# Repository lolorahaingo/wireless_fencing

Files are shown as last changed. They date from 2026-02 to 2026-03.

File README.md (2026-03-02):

<p align="center">
  
  
  
  
  
</p>

# Wireless Fencing

> Replacing the wired scoring apparatus in competitive fencing with a fully wireless system built on Raspberry Pi Pico W microcontrollers.

---

## The Problem

In competitive foil fencing, every touch is detected by an electronic scoring apparatus connected to both fencers through **15-meter retractable cables**. These cables restrict movement, require constant maintenance, and make the sport inaccessible outside of dedicated venues.

**The fundamental challenge of going wireless:** without a physical wire connecting both fencers, there is **no common electrical ground** between them. The traditional system relies on DC circuits that require this shared reference. A completely different detection approach is needed.

---

## The Solution

Each fencer wears a **Raspberry Pi Pico W** that generates unique **AC square wave frequencies** on their conductive surfaces (lame/cuirasse). When a fencer's foil tip touches the opponent's valid target, the frequency is detected through the foil's internal wiring and identified — all without any electrical connection between the two fencers.

```
                    ┌─────────────────────────────────────────────────────────┐
                    │                    NO WIRE BETWEEN FENCERS              │
                    │                                                         │
  FENCER A          │          WiFi UDP            │          FENCER B        │
 ┌──────────┐       │       ┌──────────┐           │       ┌──────────┐      │
 │ Pico W   │       │       │ CENTRAL  │           │       │ Pico W   │      │
 │          │  ─ ─ ─│─ ─ ─ >│ Pico W   │< ─ ─ ─ ─ │─ ─ ─  │          │      │
 │ Generates│       │       │          │           │       │ Generates│      │
 │ Freq A   │       │       │ Arbitrate│           │       │ Freq B   │      │
 │ on lame  │       │       │ & Score  │           │       │ on lame  │      │
 └────┬─────┘       │       └──────────┘           │       └────┬─────┘      │
      │             │                                           │            │
   ┌──┴──┐          │                                        ┌──┴──┐         │
   │LAME │ ← Freq A │    Foil tip touches lame →             │LAME │ ← Freq B
   │     │          │    Freq detected = VALID TOUCH          │     │         │
   └─────┘          │                                        └─────┘         │
                    └─────────────────────────────────────────────────────────┘
```

### Why This Works

AC signals can traverse a single wire between two independently powered boards through **parasitic capacitive coupling** — the stray capacitance between the fencer's body, the floor, and the environment acts as the return path. This was the core hypothesis of the project, and it has been **experimentally validated**.

---

## System Architecture

### Per-Fencer Electronics

Each Pico W interfaces with the standard **3-wire body cord** (FIE convention) through a custom circuit with MOSFET buffers:

```
                         PICO W (RP2040)
                    ┌─────────────────────┐
                    │                     │
    ┌───────────────┤ GP14 (PWM out)      │
    │               │                     │
    │  ┌────────────┤ GP2  (interrupt in) │
    │  │            │                     │
    │  │  ┌─────────┤ GP16 (digital in)   │
    │  │  │         │                     │
    │  │  │         │ GP17 (PWM out)  ────┼──┐  (Mode Time-Division)
    │  │  │         │ GP15 (digital out)──┼──┤  (Mode Time-Division)
    │  │  │         └─────────────────────┘  │
    │  │  │                                  │
    ▼  ▼  ▼                                  ▼
 ┌──────────────────────────────────────────────┐
 │              MOSFET BUFFER STAGE              │
 │                                               │
 │   VBUS (5V)          VBUS (5V)                │
 │      │                  │                     │
 │   [100R]             [MOSFET C] ← GP15       │
 │      │                  │                     │
 │      ├─── Line A       [100R]                 │
 │      │   (red)          │                     │
 │   [MOSFET A]            ├─── Line C           │
 │      │    ← GP14        │   (green)           │
 │     GND              [MOSFET B] ← GP17       │
 │                         │                     │
 │                        GND                    │
 │                                               │
 │   GP2 ──┬── Line B (blue)                    │
 │         │                                     │
 │      [10kR] pull-down                        │
 │         │                                     │
 │        GND                                    │
 └───────────────────────────────────────────────┘
          │         │         │
          ▼         ▼         ▼
     ┌─────────────────────────────┐
     │       BODY CORD (3 wires)   │
     │                             │
     │  Line A ──── Lame/Cuirasse  │  ← emits Freq_VALID
     │  Line B ──── Foil tip       │  ← detects frequency
     │  Line C ──── Guard/shell    │  ← button detection (DC)
     └─────────────────────────────┘
```

### Detection Logic

The foil's push-button (German tip) is **normally closed**, connecting lines B and C. When the fencer presses the tip against a target, the circuit opens:

```
 BUTTON STATE          ELECTRICAL PATH              RESULT
 ─────────────────────────────────────────────────────────────
 Not pressed      B ←→ C connected (closed)     Nothing (no touch)
 (rest)           GP16 reads LOW (pulled down
                  by GP2's 10kΩ via B→C path)

 Pressed +        B isolated, tip touches        VALID TOUCH
 tip on lame      opponent's lame → Freq_VALID   (colored light)
                  detected on GP2

 Pressed +        B isolated, tip touches        No light
 tip on guard     neutral surface → Freq_NEUTRE  (annulled)

 Pressed +        B isolated, tip in air         WHITE LIGHT
 tip in air       no frequency on GP2            (off-target)
 ─────────────────────────────────────────────────────────────
```

### Communication

```
  Fencer A                                    Fencer B
  Pico W ──── WiFi UDP ────┐  ┌──── WiFi UDP ──── Pico W
                            ▼  ▼
                      ┌──────────┐
                      │ CENTRAL  │
                      │ Pico W   │
                      │          │
                      │ • AP mode│
                      │ • Lockout│  300-350ms (FIE rules)
                      │ • Dwell  │  15ms minimum contact
                      │ • Score  │
                      │ • LEDs   │
                      └──────────┘
```

- **Protocol:** Raw UDP over WiFi (ESP-NOW is Espressif-only, incompatible with Pico W's CYW43439 chip)
- **Topology:** Central Pico W acts as WiFi Access Point
- **Target latency:** < 20ms (well within the 300ms lockout window)

---

## Engineering Journey

This project follows a rigorous **hypothesis-driven** approach: each phase validates a specific assumption before building on it. Several discoveries forced significant architecture redesigns.

### Phase 0 — Proof of Concept

| Phase | Test | Result |
|---|---|---|
| 0.1 | Frequency detection on same board (Arduino Mega) | 25 kHz detected via interrupt counting |
| 0.2 | Multi-frequency classification (20/25/40 kHz) | 3 frequencies distinguished with ±2 kHz tolerance |
| 0.3 | **Detection without common ground** (Mega → Pico W) | ~19 kHz detected through parasitic coupling |
| 0.4 | Pico-to-Pico without common ground | **20,020 Hz** — near-perfect with 10kΩ pull-down |

> **Key validation:** AC signals traverse a single wire between independently powered boards. The core hypothesis holds.

### Phase 1 — Real Equipment Integration

This is where the real engineering challenges emerged:

#### Challenge 1: Capacitive Load of the Lame

The conductive lame (target vest) forms a large parasitic capacitor with the environment. The Pico's GPIO (3.3V, 12mA) couldn't drive it at 20 kHz.

```
 Problem:  GPIO direct → lame         5-7 kHz (should be 20 kHz)
 Solution: MOSFET 2N7000 buffer       20 kHz perfect
           + 100Ω pull-up to 5V
           (10kΩ pull-up was too weak — only 0.5mA couldn't charge
            the parasitic capacitance fast enough)
```

#### Challenge 2: Parasitic B↔C Coupling Inside the Foil

Lines B and C run millimeters apart inside the blade groove, forming a parasitic capacitor. The 5V/50mA buffered signal on line C leaked to line B, making it impossible to emit on C and detect on B simultaneously.

```
 Before (4-pin design):
   GP14 → emit on A (lame)     ✓
   GP2  ← detect on B (tip)    ✗ sees C's signal via parasitic coupling
   GP16 → emit on C (guard)    ✗ leaks to B
   GP17 ← detect button        ✗ always sees 20 kHz

 After (3-pin redesign):
   GP14 → emit on A (lame)     ✓ MOSFET buffer
   GP2  ← detect on B (tip)    ✓ clean signal, no C emission
   GP16 ← detect button (DC)   ✓ exploits DC vs AC difference
```

> **Insight:** Capacitive coupling blocks DC but passes AC. The mechanical button passes DC but the parasitic coupling doesn't. By reading DC on line C, we can detect the button state without any interference.

#### Challenge 3: 5V Signal Crashing the Pico

When the foil tip touches the lame (5V via MOSFET), the signal travels back through the button to GP16, exceeding the 3.3V GPIO tolerance and causing a latch-up reset.

```
 Solution: 10kΩ series resistor on GP16
           Limits current to 0.5mA (protection diodes handle it)
           Button reading still works: 0.47V (LOW) / 2.75V (HIGH)
```

#### Challenge 4: Signal Attenuation in the Foil

The foil's internal wire (~90cm in the blade groove) runs ~1mm from the metal blade, forming a **~10nF parasitic capacitor** that shunts AC signals to ground.

```
 Frequency    Impedance (10nF)    Detection
 ──────────────────────────────────────────
 20 kHz       ~800Ω               1,700 Hz detected (massive loss)
  5 kHz       ~3.2kΩ              500-1,700 Hz (still too much loss)
  1 kHz       ~16kΩ               should pass (to be validated)
```

> **Current blocker:** Frequencies must be lowered from 20-40 kHz to ~1-3 kHz. Experimental validation pending.

### Progress Overview

```
 Phase 0   Proof of Concept                          ██████████ DONE
 Phase 1   Real Equipment Integration                ████████░░ 80% (freq. validation pending)
 Phase 2   Complete System (Simple + Time-Division)  ░░░░░░░░░░ TODO
 Phase 3   WiFi UDP Communication                    ░░░░░░░░░░ TODO
 Phase 4   FIE Arbitration Logic                     ░░░░░░░░░░ TODO
 Phase 5   Full 2-Fencer Integration                 ░░░░░░░░░░ TODO
 Phase 6   Polish (LEDs, battery, enclosure)         ░░░░░░░░░░ TODO
```

---

## Key Technical Decisions

| Decision | Choice | Why |
|---|---|-----|
| **Detection method** | Interrupt pulse counting (not Goertzel/FFT) | Signal is square wave — energy spread across harmonics makes FFT unreliable. Counting rising edges is simpler and more robust |
| **Signal generation** | RP2040 hardware PWM (not `tone()`) | `tone()` on Pico W is imprecise at high frequencies (~14 kHz instead of 20 kHz). Hardware PWM is cycle-exact |
| **Communication** | WiFi UDP (not ESP-NOW) | ESP-NOW is Espressif-only. Pico W uses Infineon CYW43439 — must use standard WiFi |
| **Button detection** | DC reading on line C (not RC filter) | RC filter approach failed due to B↔C parasitic coupling. DC reading exploits the physical difference between capacitive coupling (blocks DC) and mechanical switch (passes DC) |
| **Current buffer** | 2N7000 MOSFET + 100Ω pull-up to 5V | GPIO can't drive capacitive loads. 100Ω provides ~50mA — enough to charge/discharge parasitic capacitance at 20 kHz |
| **Receiver pull-down** | External 10kΩ (not internal ~50kΩ) | Internal pull-down too weak for 3.3V signals without common ground. 10kΩ gives perfect detection |

---

## Hardware

| Component | Role | Qty |
|---|---|-----|
| Raspberry Pi Pico W | Fencer controller + central arbiter | 3 |
| 2N7000 N-MOSFET | Current buffer for driving conductive surfaces | 3 per fencer |
| 100Ω resistors | MOSFET pull-ups + gate protection | 4 per fencer |
| 10kΩ resistors | Receiver pull-down + GP16 protection | 2 per fencer |
| Electric foil (German tip) | Standard FIE weapon | 2 |
| Body cord (3-wire) | Standard FIE body cord | 2 |
| Conductive lame | Valid target surface | 2 |

A custom PCB is being designed in **KiCad 9** (`wireless_fencing_fencer/`).

---

## Project Structure

```
wireless_fencing/
├── phase0_1_freq_interrupt/     # Frequency detection on Arduino Mega
├── phase0_2_freq_detection/     # Multi-frequency classification
├── phase0_3_no_common_gnd/      # No-common-ground validation
│   ├── mega_generator/          #   Arduino Mega signal generator
│   └── pico_receiver/           #   Pico W receiver
├── phase0_4_pico_to_pico/       # Pico-to-Pico validation
│   ├── pico_generator/          #   PWM hardware generator
│   └── pico_receiver/           #   Interrupt-based receiver
├── phase1_5_button_detect/      # Button detection (RC approach — abandoned)
├── phase1_6_button_dc/          # Button detection via DC + diagnostic tests
├── wireless_fencing_fencer/     # KiCad 9 PCB design
├── gpio_test/                   # GPIO validation utilities
├── PROJECT_PLAN.md              # Detailed engineering log (1000+ lines)
└── CLAUDE.md                    # AI assistant context file
```

---

## FIE Compliance

The system targets compliance with FIE (International Fencing Federation) timing specifications for foil:

| Parameter | FIE Specification | System Target |
|---|---|---|
| Dwell time (minimum contact) | 15ms ± 0.5ms | Measured per touch |
| Lockout time | 300-350ms | Configurable timer on central |
| Communication latency | — | < 20ms (UDP) |

---

## Tech Stack

- **Microcontroller:** Raspberry Pi Pico W (RP2040, Cortex-M0+, 133 MHz)
- **Framework:** Arduino (earlephilhower core)
- **Build system:** PlatformIO
- **Signal generation:** RP2040 hardware PWM (`hardware/pwm.h`)
- **PCB design:** KiCad 9
- **Communication:** WiFi UDP (CYW43439)

---

<p align="center">
  <i>An ongoing R&D project exploring the intersection of embedded systems, signal processing, and competitive sports.</i>
</p>

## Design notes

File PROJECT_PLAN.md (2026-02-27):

# Projet Escrime Sans Fil (Wireless Fencing)

## Contexte & Objectif

Concevoir un systeme d'arbitrage electronique sans fil pour le **fleuret** (escrime),
a base de **Raspberry Pi Pico W**, qui remplace le systeme filaire traditionnel.

La problematique principale du sans-fil est l'**absence de masse commune** entre les
deux tireurs. La solution retenue est la **detection de frequence** : chaque tireur
porte un Pico W qui genere des signaux carres AC sur ses surfaces conductrices (cuirasse
et coque du fleuret). Le fleuret adverse detecte ces frequences au contact, ce qui
permet d'identifier la nature de la touche sans connexion physique entre les tireurs.

---

## Decouvertes & Validations Cles

### Detection sans GND commun : VALIDEE (Phase 0.3 + 0.4)

**Phase 0.3** (Mega 5V → Pico W) : Arduino Mega (adaptateur secteur) genere 20 kHz
sur Pin 9, Pico W (USB sur Mac batterie) detecte sur GPIO 2. Un seul fil, aucun GND
commun. Resultat : ~18500-19700 Hz detecte (~95% des fronts). Le signal 5V du Mega
a assez d'amplitude pour franchir le seuil du GPIO recepteur.

**Phase 0.4** (Pico W 3.3V → Pico W) : Deux Pico W, alimentations separees (secteur
vs USB Mac). Resultat initial : seulement ~16 kHz detecte (~80% des fronts). Le signal
3.3V est trop faible sans GND commun pour declencher tous les fronts montants.

**Solution : resistance pull-down 10kΩ** sur le pin recepteur (entre GPIO 2 et GND
du Pico recepteur). Cette resistance tire le pin vers le bas, augmentant l'excursion
du signal couple et permettant au GPIO de detecter tous les fronts.

**Resultat avec pull-down 10kΩ** : 20 020 Hz detecte — precision quasi parfaite,
detection instantanee, equivalent au test avec GND commun.

| Test | Signal | Sans pull-down | Avec pull-down 10kΩ |
|---|---|---|---|
| Mega 5V → Pico | 20 kHz | ~19 kHz (95%) | non teste |
| Pico 3.3V → Pico | 20 kHz | ~16 kHz (80%) | **20 020 Hz (100%)** |
| Pico 3.3V → Pico (GND commun) | 20 kHz | 20 000 Hz exact | - |

**Implications** :
- L'hypothese fondamentale du projet est validee
- Le signal AC traverse un contact physique sans masse commune
- Une resistance pull-down 10kΩ cote recepteur est NECESSAIRE pour le Pico 3.3V
- Le couplage capacitif parasite suffit comme chemin de retour

### Charge capacitive de la cuirasse : RESOLU (Phase 1)

**Probleme** : Le GPIO du Pico (3.3V, ~12 mA max) ne peut pas driver la charge
capacitive de la cuirasse a 20 kHz. La cuirasse est une grande surface conductrice
qui forme un condensateur parasite avec tout ce qui l'entoure (siege, sol, corps).

**Tests sans buffer (GPIO direct)** :

| Test | Resultat |
|---|---|
| Pince croco ↔ fiche directe (sans cuirasse) | 20 kHz exact ✅ |
| Cuirasse posee sur siege plastique | 5-7 kHz fluctuant ❌ |
| Cuirasse suspendue en l'air | 10-19 kHz fluctuant ❌ |

**Solution : MOSFET 2N7000 + pull-up 100Ω vers VBUS (5V)**

La pull-up 10kΩ initialement prevue etait trop elevee — le courant (0.5 mA) ne
suffisait pas a recharger la capacitance parasite entre chaque front. Avec 100Ω
(50 mA max), les fronts montants sont assez rapides pour 20 kHz.

```
Circuit buffer valide :

        VBUS (5V)
            │
         [100Ω]  pull-up (10kΩ trop faible, 100Ω necessaire)
            │
            ├──────── vers cuirasse (fil de corps, ligne A ou C)
            │
        Drain (D)
            │
  GPIO ──[100Ω]── Gate (G)    2N7000 (MOSFET N-channel)
            │
        Source (S)
            │
          GND Pico
```

**Tests avec buffer MOSFET + pull-up 100Ω (cuirasse sur siege)** :

Detection via fleuret + fil de corps touchant la cuirasse :
- **20 000 - 20 200 Hz** sur la majorite des mesures → detection parfaite ✅
- Quelques mesures a 0 Hz → perte de contact physique (normal pour test a la main)
- Quelques mesures aberrantes (12 kHz, 24 kHz) → transitions de contact
  (etablissement/rupture pendant la fenetre de mesure)
- Le signal est detecte meme **bouton non presse** → comportement normal car
  B est connecte a la pointe en permanence, le bouton (normalement ferme) relie
  B a C mais ne bloque pas le signal vers GP2. La logique de filtrage par l'etat
  du bouton (GP20) est necessaire cote software.

**Resultat** : Le buffer MOSFET 2N7000 + pull-up 100Ω vers VBUS resout
completement le probleme de charge capacitive. Detection fiable a 20 kHz
a travers la cuirasse posee sur un siege, via fleuret + fil de corps.

**Historique des pull-up testees** :
- 10kΩ : insuffisant — signal 20-50 Hz cote drain (front montant trop lent)
- **100Ω : fonctionne** — 20 kHz detecte parfaitement

### Couplage parasite B↔C dans le fleuret : DECOUVERTE CRITIQUE (Phase 1.5)

**Probleme** : Quand on genere Freq_NEUTRE (20 kHz) sur la ligne C (coque/bati)
via le buffer MOSFET, le signal **fuit vers la ligne B** par couplage capacitif
parasite a l'interieur du fleuret. Les lignes B et C courent a quelques millimetres
l'une de l'autre dans la rainure de la lame, formant un condensateur parasite.

**Test Phase 1.5** : GP14 genere 20 kHz sur ligne C (MOSFET + pull-up 100Ω).
GP2 mesure la frequence sur ligne B. Resultat : **GP2 detecte ~20 000 Hz en
permanence**, meme bouton presse, meme pointe en l'air ne touchant rien.

Le signal 5V / 50 mA du buffer MOSFET est suffisamment puissant pour traverser
la capacite parasite interne B↔C du fleuret.

**Consequences** :
- On ne peut PAS emettre sur la ligne C et detecter proprement sur la ligne B
  en meme temps — les signaux se perturbent
- L'approche initiale (filtre RC sur GP16 pour detecter le bouton via
  presence/absence du 20 kHz sur B) est **invalidee** : le 20 kHz est
  toujours present sur B par couplage, que le bouton soit ferme ou ouvert
- L'architecture a 4 pins (2 PWM sortie + 2 GPIO entree) doit etre revue

**Solution retenue** : Architecture a 3 pins avec deux variantes incrementales :

- **Mode Simple (fondation)** : Pas de signal sur la ligne C. La ligne C sert
  uniquement a la detection du bouton par lecture DC. Pas de couplage parasite,
  detection propre sur GP2. Sacrifice : la coque n'emet pas Freq_NEUTRE
  (touche sur coque = blanche au lieu de "pas de lumiere").

- **Mode Time-Division (amelioration)** : Time-division sur la ligne C avec deux pins.
  GP17 emet le PWM via MOSFET (9 ms), puis est mis a LOW (1 ms) pendant que
  GP16 lit l'etat DC du bouton. Quand le bouton est detecte comme presse,
  GP17 reste a LOW et on bascule en detection de frequence pure sur GP2.
  La coque emet 90% du temps → ~18 kHz apparent pour le recepteur adverse
  (dans la tolerance ±2 kHz de NEUTRE).

Voir la section "Architecture par Tireur" pour les details.

### Signal 5V sur GP16 : crash du Pico (Phase 1.7)

**Probleme** : Quand GP16 (INPUT_PULLUP) est connecte a la ligne C et que la
pointe du fleuret touche la cuirasse alimentee (5V/20kHz via MOSFET), le signal
remonte par le chemin : cuirasse → pointe → ligne B → bouton ferme → ligne C → GP16.
Le signal 5V depasse la tolerance de 3.3V du GPIO, provoquant un **latch-up** et
un reset du Pico. Le crash est progressif : il survient quand le contact devient
franc et que le courant augmente.

**Solution** : Resistance serie **10kΩ** entre la ligne C et GP16. Limite le courant
a 0.5 mA max (5V / 10kΩ), ce que les diodes de protection internes supportent.
La lecture DC du bouton fonctionne toujours :
- Bouton ferme : 3.3V × 10k / (50k + 10k + 10k) ≈ 0.47V → LOW ✅
- Bouton presse : 3.3V × 50k / (50k + 10k) ≈ 2.75V → HIGH ✅

**Valide en Phase 1.7** : plus de crash avec la resistance serie.

### Attenuation du signal AC dans le fleuret : DECOUVERTE CRITIQUE (Phase 1.7)

**Probleme** : Le signal 20 kHz genere sur la cuirasse (5V via MOSFET buffer)
est **massivement attenue** en traversant le fil interne du fleuret. Au lieu de
20 kHz, GP2 ne detecte que ~1700 Hz. Meme a 5 kHz, le signal est attenue a
~500-1700 Hz.

**Tests de diagnostic** :

| Configuration | Frequence detectee |
|---|---|
| Fil direct (sans fleuret, sans cuirasse) | 20 000 Hz exact ✅ |
| Fil de corps seul (sans fleuret) | 20 000 Hz ✅ |
| Fleuret branche, pointe touche cuirasse | ~1 700 Hz ❌ |
| Fleuret branche, 5 kHz sur cuirasse | ~500-1 700 Hz ❌ |

Le fil de corps seul transmet parfaitement. C'est le **fil interne du fleuret**
(~90 cm dans la rainure de la lame) qui attenue le signal.

**Cause** : Le fil interne du fleuret court a ~1 mm de la lame metallique sur
toute sa longueur, formant un **condensateur parasite** estime a ~10 nF.
Ce condensateur shunt le signal AC vers la lame (ligne C / masse de l'arme)
avant qu'il n'atteigne le connecteur (ligne B).

A 20 kHz, l'impedance de 10 nF est : Zc = 1/(2π × 20000 × 10nF) ≈ **800Ω**
→ la majorite du signal est court-circuitee vers la lame.

A 1 kHz, l'impedance serait : Zc = 1/(2π × 1000 × 10nF) ≈ **16 kΩ**
→ beaucoup moins de fuite, le signal devrait passer.

**Implication** : Les frequences de 20-40 kHz sont **trop elevees** pour
traverser le fil interne du fleuret. Le systeme filaire classique (FIE)
fonctionne en DC (circuit normalement ferme, detection par rupture) et n'a
pas ce probleme. Notre approche par detection de frequence AC doit utiliser
des **frequences beaucoup plus basses** (1-3 kHz) pour que l'impedance du
condensateur parasite soit suffisamment elevee.

**Consequences** :
- Les frequences 20/25/40 kHz doivent etre **revues a la baisse**
- Les nouvelles frequences doivent rester suffisamment espacees pour la
  classification par plage de tolerance
- Le PWM hardware du RP2040 supporte ces frequences basses sans probleme
  (wrap plus grand)
- La fenetre de mesure de 50 ms reste adaptee (50 fronts a 1 kHz = suffisant)
- A valider experimentalement : tester 1 kHz, 2 kHz, 3 kHz a travers le fleuret

**Frequences candidates (a valider)** :

| Frequence | Usage | PWM wrap (125 MHz) | Impedance Zc (10nF) |
|---|---|---|---|
| 1 kHz | Freq_NEUTRE | 125 000 | 16 kΩ |
| 1.5 kHz | Freq_VALID_A | 83 333  | 10.6 kΩ |
| 2.5 kHz | Freq_VALID_B | 50 000  | 6.4 kΩ |

Ou :

| Frequence | Usage | PWM wrap (125 MHz) | Impedance Zc (10nF) |
|---|---|---|---|
| 2 kHz | Freq_NEUTRE | 62 500  | 8 kΩ |
| 3 kHz | Freq_VALID_A | 41 667  | 5.3 kΩ |
| 4 kHz | Freq_VALID_B | 31 250  | 4 kΩ |

Les frequences exactes seront determinees apres les tests experimentaux.

### Generation de signal sur Pico W : PWM hardware (pas tone())

`tone()` sur le Pico W (framework Earlephilhower) est imprecis aux hautes frequences
(~14-16 kHz au lieu de 20 kHz demande). Le **PWM hardware du RP2040** est exact :

```
Clock RP2040 = 125 MHz
freq = 125000000 / wrap   (diviser = 1)
20 kHz → wrap = 6250 → exact
25 kHz → wrap = 5000 → exact
40 kHz → wrap = 3125 → exact
```

Utiliser `hardware/pwm.h` avec `pwm_init()` au lieu de `tone()`.

### Methode de detection : Comptage par interruption (pas Goertzel)

**Goertzel est inadapte** pour ce projet : le signal genere est un signal carre
(pas sinusoidal), et l'energie est repartie sur les harmoniques. Le comptage
d'impulsions par interruption sur front montant est plus simple, plus fiable,
et parfaitement adapte aux signaux carres.

**Methode retenue** : `attachInterrupt(pin, callback, RISING)` + comptage sur
une fenetre temporelle (50 ms). La frequence = nombre_impulsions * (1000 / duree_ms).
Classification par plage de tolerance (±2 kHz).

### Frequences exactes

> **ATTENTION** : Les frequences 20/25/40 kHz ci-dessous sont les valeurs initiales,
> validees en Phase 0 (fil direct et fil de corps). Elles sont **trop elevees** pour
> traverser le fil interne du fleuret (attenuation massive, voir section "Attenuation
> du signal AC dans le fleuret"). De nouvelles frequences dans la plage 1-3 kHz
> doivent etre validees experimentalement (Phase 1.7bis). Le tableau ci-dessous
> reste comme reference historique.

| Frequence | Usage | Mega (prescaler 8) | Pico W (PWM hardware) |
|---|---|---|---|
| **20 000 Hz** | Freq_NEUTRE | OCR=49 → exact | wrap=6250 → exact |
| **25 000 Hz** | Freq_VALID_A | OCR=39 → exact | wrap=5000 → exact |
| **40 000 Hz** | Freq_VALID_B | OCR=24 → exact | wrap=3125 → exact |

Sur le Mega : `tone(pin, freq)` fonctionne car le timer est precis.
Sur le Pico W : utiliser le **PWM hardware** (`hardware/pwm.h`), pas `tone()`
qui est imprecis aux hautes frequences (~14-16 kHz au lieu de 20 kHz).

### Materiel : Pico W (RP2040), pas Pico 2W (RP2350)

Les cartes disponibles sont des **Raspberry Pi Pico W** (chip RP2040, Cortex-M0+),
et non des Pico 2W (chip RP2350, Cortex-M33). La distinction est importante pour
PlatformIO :
- Board ID : `rpipicow` (pas `rpipico2w`)
- Plateforme : `https://github.com/maxgerhardt/platform-raspberrypi.git`
- Core : `earlephilhower` (obligatoire pour attachInterrupt sur tous les GPIO,
  analogReadResolution, Serial USB, etc.)
- Upload : `picotool`
- La plateforme officielle `raspberrypi` de PlatformIO ne supporte PAS le Pico W

---

## Materiel Disponible

| Element | Statut |
|---|---|
| Arduino Mega | Disponible |
| Raspberry Pi Pico W x2 | Disponible |
| Fleuret electrique (tete allemande) | Disponible |
| Fil de corps | Disponible |
| Cuirasse / Lame (FIE standard) | Disponible |
| Connecteurs fleuret/fil de corps pour Arduino | Disponible |
| Resistances et condensateurs | Disponible |
| Piste metallique | NON disponible (sujet separe) |
| Oscilloscope / analyseur logique | NON disponible |
| 3eme Pico W (central) | A commander |

---

## Specifications FIE (Fleuret)

| Parametre | Valeur FIE |
|---|---|
| Temps de contact minimum (dwell) | 15 ms (+/- 0.5 ms) |
| Temps de blocage (lockout/cutout)  | 300-350 ms |
| Poids minimum sur la pointe | 500 g (4.90 N) - mecanique, non pertinent pour l'electronique |
| Temps de blocage epee (reference)  | 40 ms |

> Le lockout time est le temps entre la premiere touche enregistree et le moment
> ou le systeme se ferme. Si l'autre tireur touche dans cette fenetre, c'est une
> double touche. La latence de communication doit etre bien inferieure a 300 ms.

---

## Circuit Electrique du Fleuret — Systeme Filaire Standard

### Les 3 lignes du fil de corps (convention FIE)

| Ligne | Couleur schema | Nom FIE | Connecte a |
|---|---|---|---|
| A | Rouge | Lame | Lame/cuirasse de l'ADVERSAIRE (via appareil) |
| B | Bleu | Arme | Pointe du fleuret (via fil dans la rainure lame) |
| C | Vert | Masse | Bati du fleuret (coque/garde + lame de l'arme) |

### Bouton-poussoir (tete allemande) — NORMALEMENT FERME

- **Au repos** (bouton NON presse) : ligne B connectee a ligne C.
  Le courant circule de B vers C en permanence. Circuit ferme.
- **Bouton presse** : la connexion B <-> C est **rompue**.
  La ligne B n'est plus reliee qu'a ce qui touche la pointe physiquement.

### Fonctionnement du systeme filaire classique

| Situation | Etat electrique | Resultat |
|---|---|---|
| Bouton **non** presse | B connecte a C (ferme) | Rien |
| Bouton presse, pointe touche **lame adv.** | B se connecte a A (via le lame) | **Touche valide** (lumiere color) |
| Bouton presse, pointe touche **piste/arme**| B se connecte a C (via masse/piste)| **Rien** (annule) |
| Bouton presse, pointe touche **autre** | B n'est connecte a rien | **Touche non-valide** (blanche) |

---

## Adaptation Sans Fil — Architecture par Tireur

### Principe : 3 pins fonctionnels par Pico

Chaque Pico utilise les 3 lignes du fil de corps avec une correspondance 1:1.
La contrainte cle est que les lignes B et C ne peuvent pas etre utilisees
simultanement en emission et en detection (couplage parasite B↔C dans le fleuret).

| Pin Pico (GPIO) | Ligne fil de corps | Fonction |
|---|---|---|
| GP14 (PWM) | A (rouge) | Generation Freq_VALID sur cuirasse |
| GP2  (GPIO IN) | B (bleu) | Detection frequence par interruption |
| GP16 (GPIO IN) | C (vert) | Detection bouton par lecture DC |
| GP17 (PWM) | C (vert) | Mode Time-Division : emission Freq_NEUTRE via MOSFET |
| GP15 (GPIO OUT)  | — | Mode Time-Division : commutation alimentation pull-up |

### Mode Simple — Architecture de base (pas d'emission sur C)

C'est l'architecture de travail actuelle. La ligne C ne porte aucun signal,
elle sert uniquement a detecter l'etat du bouton par lecture DC.

**GP14 — Generation Freq_VALID (ligne A / rouge) — SORTIE PWM**
- Genere un signal carre a Freq_VALID (unique par tireur) sur la ligne A
- La ligne A est connectee a la cuirasse du tireur (via MOSFET buffer)
- Freq_VALID_A = 25 kHz, Freq_VALID_B = 40 kHz (valeurs initiales, a revoir → ~1-3 kHz)
- But : identifier une touche sur la surface valable de CE tireur

**GP2 — Detection frequence (ligne B / bleu) — ENTREE GPIO (interruption)**
- Detecte le signal qui arrive sur la pointe du fleuret via la ligne B
- N'est analyse que QUAND le bouton est presse (GP16)
- Comptage d'impulsions par interruption (RISING) sur une fenetre de 50 ms
- Pull-down 10kΩ entre GP2 et GND (indispensable sans GND commun)
- Classification par plage de frequence (±2 kHz avec 20-40 kHz, tolerance a reajuster avec nouvelles frequences) :
  - Freq_VALID adverse → touche valide
  - Aucune frequence → touche non-valide (blanche)

**GP16 — Detection bouton (ligne C / vert) — ENTREE GPIO (INPUT_PULLUP)**
- Connecte a la ligne C du fil de corps
- Exploite le fait que le couplage capacitif parasite **bloque le DC**
  tandis que le bouton mecanique **laisse passer le DC**
- Au repos (bouton ferme, B↔C connectes) : GP16 est tire vers LOW par
  la pull-down 10kΩ de GP2 (via le chemin C → bouton → B → pull-down)
  Tension : 3.3V × 10kΩ / (50kΩ + 10kΩ) ≈ 0.55V → LOW
- Bouton presse (B↔C ouvert) : GP16 flotte, tire vers HIGH par la
  pull-up interne (~50kΩ vers 3.3V) → HIGH
- Lecture par digitalRead(), instantanee

**Limitation de l'option 2** : la coque du fleuret n'emet pas Freq_NEUTRE.
Si la pointe adverse touche la coque, elle ne detecte aucune frequence →
touche blanche au lieu de "pas de lumiere". Acceptable pour le prototype.

### Mode Time-Division — Architecture amelioree (time-division sur C)

Evolution de l'option 2 avec deux pins supplementaires (GP17 + GP15) et
deux MOSFETs supplementaires. Le circuit est cable une seule fois ; le
passage Mode Simple → Mode Time-Division est purement logiciel.

**Probleme resolu** : en Mode Time-Division, la pull-up 100Ω du MOSFET d'emission
tire la ligne C a ~5V, ce qui ecrase la lecture DC du bouton par GP16.
Solution : un 3e MOSFET (C) controle par GP15 coupe l'alimentation de la
pull-up pendant la phase DETECT. Quand GP15 = LOW, la pull-up est
deconnectee de VBUS et GP16 peut lire le bouton proprement.

```
Phase EMIT   (9 ms) : GP15 = HIGH (pull-up alimentee)
                       GP17 = PWM → MOSFET B commute → 20 kHz sur ligne C
                       GP16 ignore (voit le signal PWM, non lu)

Phase DETECT (1 ms) : GP15 = LOW (pull-up coupee)
                       GP17 = LOW → MOSFET B bloque
                       GP16 en INPUT_PULLUP → lit l'etat DC du bouton

Si bouton detecte comme presse → BASCULE EN MODE FULL DETECT :
  GP15 = LOW, GP17 = LOW (circuit emission coupe)
  GP16 continue de lire le bouton
  GP2 compte la frequence en continu (pas de pollution de C)
  Jusqu'au relachement du bouton
  → Reprendre le cycle EMIT/DETECT normal
```

**Circuit complet ligne C (Mode Time-Division)** :
```
         VBUS (5V)
             │
           Drain
             │
  2N7000 (C) │    ← coupe l'alimentation de la pull-up
             │
GP15 ──[100Ω]── Gate
             │
           Source
             │
          [100Ω] pull-up
             │
             ├──────────── LIGNE C (vert) → coque/bati
             │                 │
           Drain               │
             │                 │
  2N7000 (B) │                 │
             │                 │
GP17 ──[100Ω]── Gate           │
             │                 │
           Source              GP16 [pin 21] (INPUT_PULLUP, lecture bouton)
             │
            GND
```

**Mode EMIT** (GP15 = HIGH, GP17 = PWM) :
- MOSFET C passant → VBUS connecte a la pull-up 100Ω
- MOSFET B commute en PWM → ligne C oscille entre ~5V et ~0V → 20 kHz ✅
- GP16 voit le signal PWM (ignore)

**Mode DETECT** (GP15 = LOW, GP17 = LOW) :
- MOSFET C bloque → pull-up deconnectee de VBUS
- MOSFET B bloque → ligne C deconnectee de GND
- Ligne C flotte, seuls restent :
  - Pull-up interne GP16 (~50kΩ vers 3.3V)
  - Pull-down 10kΩ de GP2 (via B, si bouton ferme)
- Bouton ferme : 3.3V × 10kΩ / (50kΩ + 10kΩ) ≈ 0.55V → LOW ✅
- Bouton presse : 3.3V (pull-up interne) → HIGH ✅

**Avantages** :
- La coque emet 90% du temps → recepteur adverse voit ~18 kHz (dans ±2 kHz de NEUTRE) ✅
- Quand le bouton est presse, le PWM est coupe → GP2 propre, pas de couplage ✅
- Latence detection bouton : max 9 ms (compatible avec dwell time FIE de 15 ms) ✅
- GP16 lit proprement le bouton en mode DETECT (pull-up coupee par GP15) ✅
- Le cablage est fait une seule fois, le passage Mode Simple → Mode Time-Division est logiciel ✅

**Note** : En Mode Simple, GP15 et GP17 sont simplement mis a LOW (output).
Les MOSFETs B et C sont bloques, le circuit emission est inactif. GP16 lit
le bouton exactement comme si les MOSFETs n'etaient pas la.

**Note** : Pendant que le bouton est presse (mode FULL DETECT), la coque n'emet
plus. C'est acceptable car a cet instant le tireur est en train de toucher
quelque chose — c'est l'adversaire qui est concerne, pas la coque de ce tireur.

### Sequence de detection (boucle principale — Mode Simple)

```
BOUCLE PRINCIPALE (chaque Pico tireur) :

1. Lire GP16 (digitalRead) : le bouton est-il presse ?
   |
   +-- NON (GP16 = LOW) → rien, retour debut boucle
   |
   +-- OUI (GP16 = HIGH) → passer a l'etape 2

2. Compter les impulsions sur GP2 (interruption RISING, fenetre 50 ms) :
   |
   +-- Comptage detecte Freq_VALID adverse → TOUCHE VALIDE
   |   Envoyer {player_id, VALID, timestamp, dwell} au central via WiFi
   |
   +-- Comptage ne detecte rien → TOUCHE NON-VALIDE (blanche)
       Envoyer {player_id, INVALID, timestamp, dwell} au central via WiFi
```

### Schema du flux electrique

```
CIRCUIT COMPLET (cable une fois, Mode Simple et Mode Time-Division) :

  === LIGNE A — Cuirasse (Freq_VALID) ===

         VBUS (5V) [pin 40]
             │
          [100Ω]
             │
             ├──── Ligne A (rouge) → cuirasse
             │
           Drain
             │
  GP14 ──[100Ω]── Gate    2N7000 (A)
             │
           Source
             │
           GND [pin 18]

  === LIGNE C — Coque (bouton + emission Mode Time-Division) ===

         VBUS (5V) [pin 40]
             │
           Drain
             │
  GP15 ──[100Ω]── Gate    2N7000 (C) ← coupe la pull-up
             │
           Source
             │
          [100Ω]
             │
             ├──── Ligne C (vert) → coque/bati
             │         │
           Drain       │
             │         │
  GP17 ──[100Ω]── Gate │    2N7000 (B) ← emission PWM
             │         │
           Source      GP16 [pin 21] (INPUT_PULLUP) ← lecture bouton
             │
           GND [pin 18]

  === LIGNE B — Pointe (detection frequence) ===

  GP2 [pin 4] ──┬── Ligne B (bleu) → pointe fleuret
                 │
              [10kΩ]
                 │
              GND [pin 3]

ETAT REPOS (bouton non presse, Mode Simple : GP15=LOW, GP17=LOW) :

  MOSFETs B et C bloques (circuit emission inactif)
  GP16 ← Ligne C ←[bouton FERME]→ Ligne B → [10kΩ pull-down] → GND
  → GP16 tire vers LOW (0.55V) → bouton NON presse

  GP2 voit rien (pas de signal sur B, pas d'emission sur C)

ETAT TOUCHE (bouton presse) :

  GP16 ← Ligne C    [bouton OUVERT]    Ligne B → GP2
  → GP16 tire vers HIGH (3.3V via pull-up interne) → bouton PRESSE

  La pointe du fleuret touche la cuirasse adverse :
  GP14 adv. --[Freq_VALID_adv]--> Cuirasse adv. --> Pointe --> Ligne B --> GP2
  → Comptage detecte Freq_VALID adverse → TOUCHE VALIDE

  OU

  La pointe ne touche rien de conducteur :
  Ligne B --> GP2 : aucune impulsion
  → TOUCHE BLANCHE (non-valide)
```

---

## Architecture Globale (2 tireurs + central)

```
TIREUR A                                          TIREUR B
+----------------------+                          +----------------------+
|  Pico W (A)          |                          |  Pico W (B)          |
|                      |                          |                      |
|  GENERE:             |                          |  GENERE:             |
|  GP14: Freq_VALID_A  |                          |  GP14: Freq_VALID_B  |
|    (25kHz) → lame A  |                          |    (40kHz) → lame B  |
|                      |                          |                      |
|  DETECTE:            |                          |  DETECTE:            |
|  GP16: bouton (DC)   |                          |  GP16: bouton (DC)   |
|  GP2: freq (GPIO     |         WiFi UDP         |  GP2: freq (GPIO     |
|    interruption)     |<------------------------>|    interruption)     |
|  Mode Time-Division:           |                          |  Mode Time-Division:           |
|  GP17: emit coque    |                          |  GP17: emit coque    |
|  GP15: alim pull-up  |                          |  GP15: alim pull-up  |
+----------+-----------+                          +----------+-----------+
           |                                                  |
           |              +--------------+                    |
           +------------->|  CENTRAL     |<-------------------+
                          |  (Pico W     |
                          |   ou Mega)   |
                          |              |
                          |  - Arbitrage |
                          |  - Lockout   |
                          |  - Affichage |
                          |    lumieres  |
                          +--------------+
```

### Frequences

> **NOTE** : Les valeurs 20/25/40 kHz ci-dessous sont les frequences initiales.
> Elles doivent etre **abaissees a ~1-3 kHz** suite a la decouverte de l'attenuation
> par le fil interne du fleuret (Phase 1.7). Nouvelles valeurs a determiner
> experimentalement en Phase 1.7bis.

- **Freq_VALID_A** (25 kHz → a revoir) : frequence unique du tireur A, generee sur
  sa cuirasse (ligne A). Si le fleuret de B detecte cette frequence,
  c'est une touche valide de B sur A.
- **Freq_VALID_B** (40 kHz → a revoir) : frequence unique du tireur B, generee sur
  sa cuirasse (ligne A). Si le fleuret de A detecte cette frequence,
  c'est une touche valide de A sur B.
- **Freq_NEUTRE** (20 kHz → a revoir) : frequence reservee pour les surfaces neutres.
  Non emise en Mode Simple. En Mode Time-Division, emise sur la coque (ligne C) par
  time-division (90% du temps). Sera aussi utilisee sur la piste metallique
  (quand disponible).

### Logique de Detection (tableau de verite)

**Mode Simple (architecture de base)** :

| Bouton presse ? | Frequence sur GP2 | Resultat |
|---|---|---|
| Non | (non lu) | Rien (pas de touche) |
| Oui | Freq_VALID adverse | **Touche valide** (lumiere coloree) |
| Oui | Aucune frequence | **Touche non-valide** (lumiere blanche)|

**Mode Time-Division (amelioration future)** :

| Bouton presse ? | Frequence sur GP2 | Resultat |
|---|---|---|
| Non | (non lu) | Rien (pas de touche) |
| Oui | Freq_VALID adverse | **Touche valide** (lumiere coloree) |
| Oui | Freq_NEUTRE | **Pas de lumiere** (piste/coque) |
| Oui | Aucune frequence | **Touche non-valide** (lumiere blanche)|

---

## Detection de Frequence : Approche Technique

### Methode : Comptage d'impulsions par interruption

Le signal genere est un signal carre. La detection se fait par comptage de
fronts montants (RISING) via interruption materielle sur un pin GPIO.

**Principe** :
1. Configurer le pin en INPUT avec `attachInterrupt(pin, callback, RISING)`
2. Ajouter une **resistance pull-down 10kΩ** entre le pin et GND (indispensable
   pour la detection sans GND commun en 3.3V)
3. L'ISR incremente un compteur a chaque front montant
4. Toutes les 50 ms, lire le compteur et le remettre a zero (section atomique)
5. Frequence = compteur * (1000 / duree_fenetre_ms)
6. Classifier la frequence par plage de tolerance (±2 kHz)

**Avantages** :
- Extremement simple a implementer
- Fonctionne parfaitement avec des signaux carres
- Pas de calcul flottant, pas de buffer, pas de FFT
- Valide sur le Pico W (interruption sur n'importe quel GPIO)

**Pourquoi pas Goertzel / FFT** :
- Le signal est carre, pas sinusoidal → energie repartie sur les harmoniques
- Le comptage par interruption est plus direct et plus fiable pour ce cas
- Goertzel necessite un ADC rapide et du calcul flottant → surcharge inutile

### Chemin du Signal (touche valide)

1. Le Pico adverse genere Freq_VALID sur sa ligne A (Pin 2 PWM)
2. Ce signal est present sur le lame/cuirasse de l'adversaire
3. Le fleuret du tireur touche le lame → le signal entre par la pointe
4. Le bouton-poussoir est presse → B <-> C rompu → B est isole
5. Le signal remonte par la ligne B jusqu'au Pin 4 (GPIO) du Pico du tireur
6. L'interruption compte les fronts montants → frequence identifiee
7. → Touche valide envoyee au central

---

## Communication Sans Fil

### Protocole : WiFi UDP brut

**IMPORTANT** : ESP-NOW n'est PAS disponible sur le Pico W (c'est un protocole
Espressif pour ESP32). Le Pico W utilise un chip CYW43439 (Infineon).

**Solution retenue** : UDP brut sur WiFi
- Le Pico central agit comme Access Point WiFi
- Les deux Pico tireurs s'y connectent
- Communication par paquets UDP
- Latence typique : 2-10 ms (largement suffisant pour le lockout de 300 ms)

### Format de Message (a affiner)

```
struct TouchEvent {
    uint8_t  player_id;      // 1 ou 2
    uint8_t  touch_type;     // VALID=1, INVALID=2, NEUTRAL=3, NONE=0
    uint32_t timestamp_ms;   // timestamp local du Pico
    uint16_t dwell_time_ms;  // duree de contact mesuree
};
```

---

## Plan d'Execution par Phases

### Phase 0 : Proof of Concept — Generation & Detection de Frequence

#### Phase 0.1 : Detection sur meme carte (Arduino Mega) — TERMINE
**Plateforme** : Arduino Mega
**Resultat** : Signal carre genere par tone() detecte par interruption sur la meme carte.
Comptage d'impulsions fonctionnel. Mais test biaise : GND commun entre emetteur et recepteur.
**Code** : `phase0_1_freq_interrupt/`

#### Phase 0.2 : Multi-frequences sur meme carte (Arduino Mega) — TERMINE
**Plateforme** : Arduino Mega
**Resultat** : Distinction de 3 frequences (16/25/40 kHz) par comptage + classification.
Decouverte : 16 kHz n'est pas exact sur le timer du Mega (15873 Hz reel).
Frequences corrigees : 20/25/40 kHz (toutes exactes).
**Code** : `phase0_2_freq_detection/`

#### Phase 0.3 : Detection sans GND commun (Mega → Pico W) — TERMINE
**Plateforme** : Arduino Mega (generateur) + Raspberry Pi Pico W (recepteur)
**Objectif** : Valider que le signal traverse sans masse commune
**Setup** : Mega sur adaptateur secteur, Pico W sur USB Mac (batterie).
Un seul fil entre Pin 9 (Mega) et GPIO 2 (Pico W). Aucun fil GND.
**Resultat** : Detection fiable a ~18500-19700 Hz (classifie NEUTRE 20 kHz).
Le couplage capacitif parasite suffit comme chemin de retour.
**Code** : `phase0_3_no_common_gnd/mega_generator/` et `phase0_3_no_common_gnd/pico_receiver/`

**Checkpoint** : Hypothese fondamentale du projet VALIDEE — detection sans GND commun fonctionne.

#### Phase 0.4 : Detection Pico → Pico (sans Arduino Mega) — TERMINE
**Plateforme** : 2x Raspberry Pi Pico W
**Objectif** : Valider la generation ET la detection sur Pico W uniquement.
**Setup** : Pico generateur (adaptateur secteur) sur GPIO 15, Pico recepteur
(USB Mac) sur GPIO 2. Un seul fil + resistance pull-down 10kΩ cote recepteur.
**Code** : `phase0_4_pico_to_pico/pico_generator/` et `phase0_4_pico_to_pico/pico_receiver/`

**Decouvertes** :
- `tone()` est imprecis sur le Pico W → utiliser PWM hardware (`hardware/pwm.h`)
- Sans pull-down : seulement ~80% des fronts detectes (~16 kHz au lieu de 20 kHz)
  avec montee progressive (capacites parasites qui se chargent)
- Pull-down interne (INPUT_PULLDOWN, ~50kΩ) : insuffisant, meme resultat
- **Pull-down externe 10kΩ** : detection parfaite (20 020 Hz), instantanee

**Circuit recepteur** :
```
GPIO 2 ──┬── fil signal vers generateur
          │
         [10kΩ]
          │
GND ──────┘
```

**Checkpoint** : Le systeme fonctionne entierement sur Pico W avec pull-down 10kΩ.

---

### Phase 1 : Detection via Fil de Corps + Fleuret — EN COURS
**Plateforme** : 2x Raspberry Pi Pico W
**Objectif** : Valider le chemin complet du signal a travers l'equipement reel
**Prerequis** : Pull-down 10kΩ sur le pin de detection (valide en Phase 0.4),
PWM hardware pour la generation de signal, buffer MOSFET 2N7000 + pull-up 100Ω.

- **1.1** : Pico generateur genere 20 kHz (PWM hardware) sur un GPIO connecte
         a une surface conductrice (feuille alu, cuirasse, ou lame) — **TERMINE**
- **1.2** : Brancher le fleuret + fil de corps au Pico recepteur via les connecteurs — **TERMINE**
- **1.3** : Toucher la surface conductrice avec la pointe du fleuret
         et verifier que le Pico recepteur detecte la frequence sur la ligne B — **TERMINE**
         Note : le signal est detecte meme bouton non presse (normal, voir 1.5)
- **1.4** : Tester avec la cuirasse reelle comme surface emettrice — **TERMINE**
         GPIO direct : echec (5-7 kHz). Buffer MOSFET 2N7000 + pull-up 100Ω : **20 kHz** ✅
- **1.5** : Tester la detection du bouton — **ECHEC de l'approche RC, DECOUVERTE CRITIQUE**
         Test initial : filtre RC (10kΩ + 100nF) sur GP16 pour lisser le 20 kHz
         de la ligne C et detecter le bouton par presence/absence de signal sur B.
         Resultat : GP16 reste LOW en permanence (tension DC lissee trop faible).
         De plus, GP2 detecte ~20 kHz meme bouton presse et pointe en l'air →
         **couplage capacitif parasite B↔C** a l'interieur du fleuret. Le signal
         5V/50mA du buffer MOSFET sur C fuit vers B par la capacite parasite
         entre les deux lignes qui courent cote a cote dans la lame.
         → Approche RC **abandonnee**. Architecture revue : pas d'emission sur C
         (Mode Simple), detection du bouton par lecture DC sur la ligne C.
         Voir section "Couplage parasite B↔C" et "Architecture par Tireur".
         **Code** : `phase1_5_button_detect/` (code du test RC, obsolete)
- **1.6** : Tester la detection du bouton par lecture DC sur GP16 (Mode Simple) — **TERMINE** ✅
         GP16 en INPUT_PULLUP connecte a la ligne C. Pas d'emission sur C.
         Bouton ferme → GP16 tire vers LOW (via pull-down 10kΩ de GP2 sur B).
         Bouton presse → GP16 tire vers HIGH (pull-up interne).
         **Resultat** : transitions propres, detection fiable. Valide.
         **Code** : `phase1_6_button_dc/`
- **1.7** : Tester la detection de frequence propre sur GP2 (sans emission sur C) — **PARTIELLEMENT TERMINE**
         Verifier que GP2 ne voit aucun signal au repos (pas de couplage parasite)
         et detecte correctement Freq_VALID quand la pointe touche la cuirasse.
         **Decouvertes** :
         - GP16 crash avec signal 5V → resolu par resistance serie 10kΩ ✅
         - Avalanche d'interruptions au repos (20k ISR/s) → resolu par detachInterrupt ✅
         - **Signal AC massivement attenue par le fil interne du fleuret** → 20 kHz reduit a ~1700 Hz ❌
         - Les frequences 20-40 kHz sont trop elevees → doivent etre abaissees a 1-3 kHz
         Voir sections "Signal 5V sur GP16" et "Attenuation du signal AC dans le fleuret".
- **1.7bis** : Tester des frequences basses (1-3 kHz) a travers le fleuret — A faire
         Valider experimentalement quelle plage de frequences traverse le fil interne
         du fleuret avec suffisamment d'amplitude pour etre detectee.
- **1.8** : Connecter Freq_VALID sur la cuirasse (ligne A via MOSFET buffer)
         et verifier la boucle complete : bouton presse → detection freq → classification — A faire

**Checkpoint** : Le signal traverse proprement l'equipement d'escrime, le bouton
est detecte par lecture DC, et Freq_VALID est identifiee a travers le fil de corps

---

### Phase 2 : Systeme complet sur Pico W (Mode Simple → Mode Time-Division)
**Plateforme** : Raspberry Pi Pico W
**Objectif** : Faire tourner le systeme complet sur le Pico

- **2.1** : Generation Freq_VALID sur le Pico (PWM hardware)
         GP14 → Freq_VALID sur ligne A (via MOSFET buffer vers cuirasse)
- **2.2** : Detection bouton sur GP16 (INPUT_PULLUP, lecture DC ligne C)
- **2.3** : Detection frequence sur GP2 (GPIO interruption RISING, ligne B)
- **2.4** : Valider la boucle complete : bouton → comptage → identification
- **2.5** : Tester avec le materiel reel (cuirasse + fleuret)
- **2.6** : Implementer le time-division sur ligne C (Mode Time-Division) :
         GP15 = HIGH + GP17 = PWM (9 ms) → emission Freq_NEUTRE sur coque
         GP15 = LOW + GP17 = LOW (1 ms) → GP16 lit le bouton
         Bascule en FULL DETECT quand bouton presse (GP15=LOW, GP17=LOW).
- **2.7** : Valider que le recepteur adverse voit ~18 kHz sur la coque (Mode Time-Division)

**Checkpoint** : Le Pico detecte le bouton et distingue les frequences a travers l'equipement

---

### Phase 3 : Communication WiFi UDP
**Plateforme** : 2x Raspberry Pi Pico W
**Objectif** : Etablir une communication rapide entre 2 Pico

- **3.1** : Configurer un Pico comme Access Point WiFi
- **3.2** : Connecter le second Pico au premier
- **3.3** : Envoyer des paquets UDP avec les evenements de touche
- **3.4** : Mesurer la latence aller-retour (objectif : < 20 ms)
- **3.5** : Definir le protocole de message (type touche, timestamp, ID tireur)

**Checkpoint** : Latence < 20 ms confirmee

---

### Phase 4 : Logique d'Arbitrage
**Plateforme** : Pico central (ou Arduino Mega)
**Objectif** : Implementer les regles FIE sur le central

- **4.1** : Implementer le timer de lockout (300-350 ms, configurable)
- **4.2** : Implementer le dwell time (15 ms minimum de contact)
- **4.3** : Logique : 1ere touche -> demarrer lockout -> attendre 2eme touche ou expiration
- **4.4** : Determiner le resultat (valide/invalide/double/rien) et commander les lumieres

**Checkpoint** : L'arbitrage respecte les timings FIE

---

### Phase 5 : Integration Complete 2 Tireurs
**Objectif** : Deux tireurs complets face a face

- Chaque Pico genere Freq_VALID sur sa cuirasse (GP14 PWM → ligne A via MOSFET)
- Chaque Pico detecte le bouton par lecture DC (GP16 INPUT_PULLUP → ligne C)
- Chaque Pico detecte la frequence au bout du fleuret (GP2 interruption → ligne B)
- Si Mode Time-Division implemente : chaque Pico emet Freq_NEUTRE sur sa coque par
  time-division (GP15 alim + GP17 PWM via MOSFET, GP16 lecture bouton)
- Les evenements remontent au central en WiFi UDP
- Le central arbitre et allume les lumieres

**Checkpoint** : Simulation d'assaut complete fonctionnelle

---

### Phase 6 : Polish & Finitions
**Objectif** : Rendre le systeme utilisable en conditions reelles

- LEDs RGB ou NeoPixels pour les lumieres (rouge/vert/blanc)
- Buzzer pour signaler les touches
- Boitier imprime 3D pour les Pico
- Batterie LiPo pour les Pico portes par les tireurs
- Interface d'affichage sur le central

---

## Composants Supplementaires Recommandes

| Composant | Usage | Prix approx. |
|---|---|---|
| 3eme Pico W | Central d'arbitrage | ~8 EUR |
| LEDs RGB ou NeoPixels | Signalisation des touches | ~3 EUR |
| Buzzer piezo | Signal sonore | ~1 EUR |
| Batteries LiPo 3.7V + chargeur | Alimentation portee | ~10 EUR x2 |
| Condensateurs 100nF, 10uF | Filtrage des signaux | ~2 EUR |
| Resistances (1k, 10k, 100k ohms) | Diviseurs de tension, pull-ups | ~2 EUR |
| Transistor MOSFET 2N7000 x3 + resistances 100Ω x4 | **Buffers de courant** : 1x ligne A (cuirasse), 2x ligne C (emission + alim) | ~3 EUR |

---

## Risques Identifies

| Risque | Impact | Mitigation |
|---|---|---|
| Signal trop attenue a travers la lame | **CONFIRME** | Le fil interne du fleuret forme un condensateur parasite (~10 nF) qui shunt le signal AC vers la lame. A 20 kHz, Zc ≈ 800Ω → signal massivement attenue. **Solution : baisser les frequences a 1-3 kHz** (Zc ≈ 8-16 kΩ). A valider en Phase 1.7bis. Augmenter l'amplitude ne resout pas le probleme (le signal est perdu dans le fleuret, pas a la source). |
| GPIO ne peut pas driver la cuirasse (charge capacitive) | **RESOLU** | Buffer 2N7000 + pull-up 100Ω vers VBUS 5V — valide en Phase 1 |
| Couplage capacitif parasite B↔C dans le fleuret | **RESOLU** | Ne pas emettre sur C et detecter sur B en meme temps. Mode Simple : pas d'emission sur C. Mode Time-Division : time-division avec bascule en full detect quand bouton presse. Decouvert en Phase 1.5. |
| Bruit electrique parasite | Moyen | Comptage par interruption est robuste au bruit |
| Latence WiFi trop elevee | Moyen | UDP brut sans overhead HTTP ; mesurer en Phase 3 |
| Interference entre les 2 frequences | Moyen | Frequences suffisamment espacees (a revalider avec nouvelles frequences basses) |
| Signal trop faible pour declencher interruption | **RESOLU** | Pull-down 10kΩ sur le pin recepteur (valide en Phase 0.4) |
| Detection bouton par DC : niveaux de tension insuffisants | **RESOLU** | Pull-up interne (50kΩ) vs pull-down externe (10kΩ) donne 0.55V (LOW) vs 3.3V (HIGH). **Valide en Phase 1.6** : transitions propres, detection fiable. |
| Signal 5V sur GP16 provoque crash/latch-up du Pico | **RESOLU** | Quand la pointe touche la cuirasse (5V via MOSFET), le signal remonte via B → bouton → C → GP16. **Solution : resistance serie 10kΩ** sur GP16 (limite le courant a 0.5 mA). Valide en Phase 1.7. |
| Avalanche d'interruptions au repos (20k ISR/s) | **RESOLU** | Au repos (bouton ferme, B↔C connectes), le signal 20 kHz atteint GP2 via le fil de corps → saturation CPU → watchdog reset. **Solution : detachInterrupt quand bouton non presse**, attachInterrupt uniquement quand bouton presse. |

---

## Decisions Techniques Prises

1. **Methode de detection** : Comptage d'impulsions par interruption (RISING)
   - Goertzel/FFT ecartes : inadaptes aux signaux carres, surcharge inutile
2. **Generation de signal** : PWM hardware du RP2040 (`hardware/pwm.h`)
   - `tone()` ecarte sur Pico W : imprecis aux hautes frequences
3. **Pull-down 10kΩ** sur le pin de detection (indispensable sans GND commun en 3.3V)
   - Pull-down interne (~50kΩ) insuffisant
4. **Communication** : WiFi UDP brut (pas ESP-NOW, incompatible Pico W)
5. **Topologie WiFi** : Le central est Access Point, les tireurs sont clients
6. **Frequences** : 3 frequences exactes (20 kHz, 25 kHz, 40 kHz)
7. **Freq_NEUTRE** : reservee pour les surfaces neutres (coque, piste).
   Non emise en Mode Simple. Emise par time-division en Mode Time-Division.
8. **Approche incrementale** : valider la detection de frequence AVANT tout le reste
9. **Detection bouton** : lecture DC sur la ligne C via GP16 (INPUT_PULLUP).
   Le couplage capacitif parasite bloque le DC, le bouton mecanique le laisse
   passer. Approche par filtre RC **abandonnee** (Phase 1.5).
10. **Separation des fonctions** : 5 pins par Pico (3 actifs en Mode Simple, 5 en Mode Time-Division)
    - GP14 (PWM sortie) → MOSFET A → ligne A → Freq_VALID sur cuirasse
    - GP2 (GPIO entree + pull-down 10kΩ) → ligne B → detection frequence (interruption)
    - GP16 (GPIO entree INPUT_PULLUP) → ligne C → detection bouton (DC)
    - GP17 (PWM sortie, Mode Time-Division) → MOSFET B → ligne C → emission Freq_NEUTRE
    - GP15 (GPIO sortie, Mode Time-Division) → MOSFET C → coupe alimentation pull-up ligne C
    En Mode Simple, GP15 et GP17 sont a LOW (MOSFETs B et C bloques, circuit inactif).
    En Mode Time-Division, GP15 et GP17 controlent l'emission sur la coque par time-division.
    Le circuit est cable une seule fois, le passage Mode Simple → Mode Time-Division est logiciel.
11. **Buffer de courant** : MOSFET 2N7000 + pull-up **100Ω** vers VBUS (5V).
    Utilise sur ligne A (MOSFET A, cuirasse) et ligne C (MOSFETs B+C, coque).
    Pull-up 10kΩ insuffisante (front montant trop lent). 100Ω fournit ~50 mA,
    suffisant pour charger/decharger la capacitance parasite a 20 kHz.
    Le signal est inverse (GPIO HIGH → Drain a GND, GPIO LOW → Drain a 5V)
    mais sans impact sur la detection par comptage de fronts.
    En Mode Time-Division, le MOSFET C (GP15) coupe l'alimentation de la pull-up pendant
    la phase DETECT pour que GP16 puisse lire le bouton sans interference.
12. **Pas d'emission et detection simultanees sur B et C** : le couplage capacitif
    parasite entre les lignes B et C a l'interieur du fleuret rend impossible
    l'emission sur C et la detection sur B en meme temps. Decouvert en Phase 1.5.
    Solution : Mode Simple (pas d'emission sur C) ou Mode Time-Division (time-division).
13. **Protection GP16 par resistance serie 10kΩ** : quand la pointe touche la cuirasse
    (5V via MOSFET), le signal remonte jusqu'a GP16 via le bouton ferme. Le 5V depasse
    la tolerance 3.3V du GPIO. La resistance serie 10kΩ limite le courant a 0.5 mA,
    ce que les diodes de protection internes supportent. La lecture DC du bouton
    fonctionne toujours (0.47V LOW / 2.75V HIGH). Decouvert et resolu en Phase 1.7.
14. **Gestion des interruptions par etat du bouton** : au repos (bouton ferme),
    le signal AC atteint GP2 via le fil de corps → 20k ISR/s → crash. Solution :
    detachInterrupt quand bouton non presse, attachInterrupt uniquement quand
    bouton presse. Decouvert et resolu en Phase 1.7.
15. **Frequences a abaisser de 20-40 kHz vers 1-3 kHz** : le fil interne du fleuret
    (~90 cm dans la rainure de la lame) forme un condensateur parasite ~10 nF avec
    la lame metallique. A 20 kHz, Zc ≈ 800Ω → signal massivement attenue. A 1 kHz,
    Zc ≈ 16 kΩ → beaucoup moins de fuite. Nouvelles frequences a valider
    experimentalement en Phase 1.7bis. Decouvert en Phase 1.7.

---

## Notes Techniques Importantes

### Configuration PlatformIO pour Pico W

```ini
[env:rpipicow]
platform          = https://github.com/maxgerhardt/platform-raspberrypi.git
board             = rpipicow
framework         = arduino
board_build.core  = earlephilhower
monitor_speed     = 115200
upload_protocol   = picotool
```

**Attention** : La plateforme officielle `raspberrypi` de PlatformIO ne supporte
pas le Pico W. Il faut utiliser le fork de maxgerhardt avec le core earlephilhower.

**Upload** : Maintenir le bouton BOOTSEL enfonce en branchant l'USB, puis relacher.
Le Pico apparait comme un lecteur USB. PlatformIO upload via picotool automatiquement.

**Serial USB** : Ne pas utiliser `while (!Serial)` qui peut bloquer indefiniment.
Utiliser `delay(2000)` ou `delay(3000)` apres `Serial.begin()` pour laisser le
temps au CDC USB de s'initialiser.

### Tete Allemande (Bouton du Fleuret)
Le bouton-poussoir a la pointe du fleuret est de type **normalement ferme** :
- Au repos : ligne B connectee a ligne C (circuit ferme)
- Bouton presse : ligne B deconnectee de ligne C (circuit ouvert)

La detection du bouton se fait par **lecture DC sur GP16** (connecte a la ligne C,
configure en INPUT_PULLUP). Le couplage capacitif parasite entre B et C bloque
le DC mais laisse passer l'AC — le bouton mecanique fait l'inverse (laisse
passer le DC). On exploite cette difference :
- Bouton ferme : GP16 tire vers LOW par la pull-down 10kΩ de GP2 (via B)
- Bouton presse : GP16 tire vers HIGH par la pull-up interne (~50kΩ)

En Mode Time-Division, GP17 pilote le MOSFET d'emission et GP15 coupe l'alimentation
de la pull-up pendant la phase DETECT. GP16 reste dedie a la lecture du bouton.
Le circuit est cable une seule fois (3 MOSFETs 2N7000 sur la ligne C).

**Approche abandonnee** : filtre RC (10kΩ + 100nF) pour lisser le 20 kHz
et detecter le bouton par presence/absence de signal. Invalidee par le
couplage parasite B↔C (le signal est toujours present, meme bouton ouvert).

### Piste Metallique (Sujet Separe)
La piste metallique n'est pas disponible pour les tests actuels. Elle sera traitee
separement. En theorie, il suffit de generer Freq_NEUTRE sur la piste, de la meme
maniere que sur les coques des fleurets. La detection de Freq_NEUTRE au bout du
fleuret annule la touche (pas de lumiere).

### Coque du Fleuret vs Cuirasse
- La **coque** (garde) du fleuret est la partie metallique qui protege la main.
  Elle fait partie du **bati** de l'arme, connecte a la ligne C.
  → En Mode Simple : ne porte aucun signal (ligne C = detection bouton uniquement)
  → En Mode Time-Division : porte **Freq_NEUTRE** par time-division (90% du temps)
- La **cuirasse** (lame) est le gilet conducteur qui couvre la surface valable.
  Connectee a la ligne A.
  → Porte **Freq_VALID** (touche valide si detectee par l'adversaire)

### Correspondance Lignes / Pins / Fonctions (resume)

```
Fil de corps :          Pico :                    Connecte a :
+--------+              +----------+              +------------------+
| A (rouge) |---------->| GP14 (PWM)  |--MOSFET A-->| Cuirasse       |
| B (bleu)  |---------->| GP2  (GPIO) |             | Pointe fleuret |
| C (vert)  |---------->| GP16 (GPIO) |             | Bati/Coque     |
|           |---------->| GP17 (PWM)  |--MOSFET B-->| (emission)     |
|           |           | GP15 (GPIO) |--MOSFET C-->| (alim pull-up) |
+--------+              +----------+              +------------------+

Mode Simple : GP14=PWM, GP2=interrupt in, GP16=digitalRead in, GP15=LOW, GP17=LOW
Mode Time-Division : GP14=PWM, GP2=interrupt in, GP16=digitalRead in, GP15=commute, GP17=PWM
```

### Pinout Pico W (reference rapide)

```
                    ┌──────── micro USB ────────┐
                    │                           │
            GP0  [1]│●                         ●│[40] VBUS (5V)
            GP1  [2]│●                         ●│[39] VSYS
            GND  [3]│●                         ●│[38] GND
            GP2  [4]│●                         ●│[37] 3V3_EN
            GP3  [5]│●                         ●│[36] 3V3 OUT
            GP4  [6]│●                         ●│[35] ADC_VREF
            GP5  [7]│●                         ●│[34] GP28 / ADC2
            GND  [8]│●                         ●│[33] AGND
            GP6  [9]│●                         ●│[32] GP27 / ADC1
           GP7 [10]│●                         ●│[31] GP26 / ADC0
           GP8 [11]│●                         ●│[30] RUN
           GP9 [12]│●                         ●│[29] GP22
           GND [13]│●                         ●│[28] GND
          GP10 [14]│●                         ●│[27] GP21
          GP11 [15]│●                         ●│[26] GP20
          GP12 [16]│●                         ●│[25] GP19
          GP13 [17]│●                         ●│[24] GP18
           GND [18]│●                         ●│[23] GND
          GP14 [19]│●                         ●│[22] GP17
          GP15 [20]│●                         ●│[21] GP16
                    │          ┌─────┐          │
                    │          │DEBUG│          │
                    └──────────┴─────┴──────────┘
```

---

## Etat d'Avancement

| Phase | Description | Statut |
|---|---|---|
| Phase 0.1 | Detection sur meme carte (Mega) | TERMINE |
| Phase 0.2 | Multi-frequences sur meme carte (Mega) | TERMINE |
| Phase 0.3 | Detection sans GND commun (Mega → Pico W) | TERMINE |
| Phase 0.4 | Detection Pico → Pico (sans Mega) | TERMINE |
| Phase 1 | Detection via fil de corps + fleuret | EN COURS — buffer MOSFET valide ✅, detection cuirasse OK ✅, couplage B↔C decouvert ✅, architecture revue ✅, detection bouton DC validee (1.6) ✅, crash GP16 resolu (1.7) ✅, avalanche ISR resolue (1.7) ✅, **BLOQUANT : attenuation AC dans fleuret → frequences 20-40 kHz trop elevees, a baisser vers 1-3 kHz (1.7bis)** |
| Phase 2 | Systeme complet sur Pico W (Mode Simple → Time-Division) | A faire |
| Phase 3 | Communication WiFi UDP | A faire |
| Phase 4 | Logique d'arbitrage | A faire |
| Phase 5 | Integration complete 2 tireurs | A faire |
| Phase 6 | Polish (LEDs, buzzer, boitier, batterie) | A faire |

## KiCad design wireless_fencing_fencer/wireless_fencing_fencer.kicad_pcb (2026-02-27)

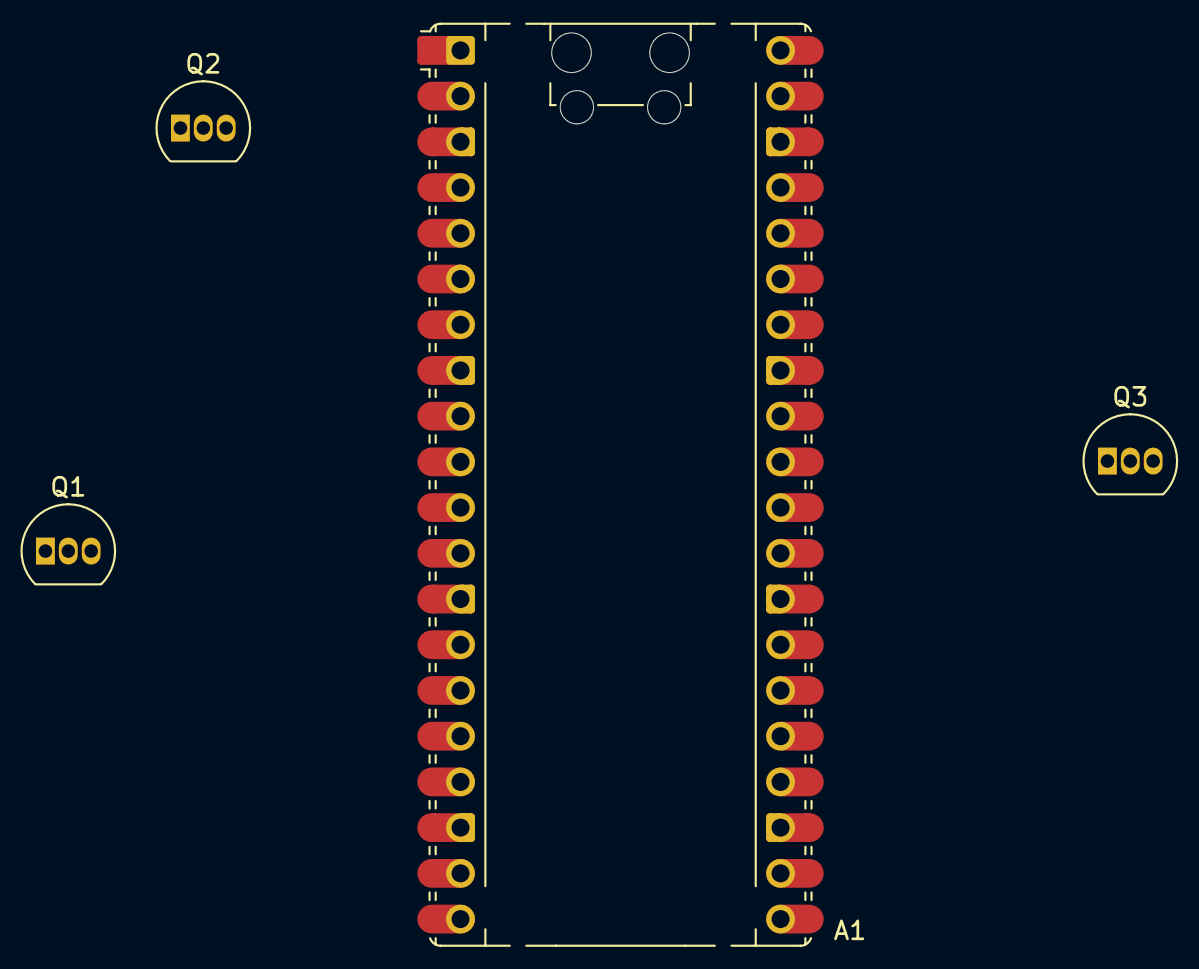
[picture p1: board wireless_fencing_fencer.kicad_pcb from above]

Board: 2 copper layers, 4 parts (0 on the bottom side), 2 nets, no tracks yet.

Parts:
A1: RaspberryPi_Pico; RaspberryPi_Pico_Common_Unspecified
Q1, Q2, Q3: 2N7000; TO-92_Inline

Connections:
GND: A1.3 (GND), A1.8 (GND), A1.13 (GND), A1.18 (GND), A1.23 (GND), A1.28 (GND), A1.38 (GND)
unnamed: A1.14 (GPIO10), Q1.2 (G)

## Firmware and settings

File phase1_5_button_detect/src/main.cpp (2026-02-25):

// =============================================================================
// Phase 1.5 — Détection du bouton + classification de touche
// Projet : Escrime sans fil
// =============================================================================
//
// RÔLE :
//   1. Génère Freq_NEUTRE (20 kHz) en continu sur la coque (ligne C)
//      via MOSFET 2N7000 + pull-up 100Ω vers VBUS
//   2. Détecte l'appui du bouton du fleuret (tête allemande, normalement fermé)
//      via filtre RC (10kΩ + 100nF) sur GP16 → digitalRead
//   3. Quand le bouton est pressé, mesure la fréquence sur GP2 (ligne B)
//      et classifie la touche (valide / neutre / blanche)
//
// CÂBLAGE :
//
//   === Génération Freq_NEUTRE (20 kHz) → ligne C ===
//
//           VBUS (5V) [pin 40]
//               │
//            [100Ω] pull-up
//               │
//               ├──── ligne C (vert) → coque/bâti
//               │
//           Drain (D)
//               │
//   GP14 ──[100Ω]── Gate (G)    2N7000
//               │
//           Source (S)
//               │
//           GND [pin 18]
//
//   === Détection fréquence + bouton (ligne B) ===
//
//                            [10kΩ]        [100nF]
//   Ligne B (bleu) ───┬──── [R] ────┬──── [C] ──── GND
//                     │              │
//                     │           GP16 [pin 21] (bouton, digitalRead)
//                     │
//                     ├──── GP2 (détection freq, interruption)
//                     │
//                   [10kΩ] pull-down
//                     │
//                    GND
//
// FONCTIONNEMENT :
//   - Au repos (bouton non pressé) : B↔C fermé, le signal 20 kHz de C
//     circule vers B. Le filtre RC lisse ce signal → GP16 = HIGH.
//     GP2 voit 20 kHz mais on l'ignore (bouton pas pressé).
//
//   - Bouton pressé : B↔C ouvert, plus de signal de C sur B.
//     Le condensateur se décharge → GP16 = LOW.
//     GP2 voit ce qui arrive par la pointe du fleuret :
//       → Freq_VALID adverse (25/40 kHz) = TOUCHE VALIDE
//       → Freq_NEUTRE (20 kHz)           = PAS DE LUMIÈRE (coque/piste)
//       → Rien (0 Hz)                    = TOUCHE BLANCHE (non-valide)
//
// =============================================================================

#include <Arduino.h>
#include <hardware/pwm.h>
#include <hardware/clocks.h>

// =============================================================================
// CONFIGURATION DES PINS
// =============================================================================

const uint PIN_PWM_NEUTRE = 14;   // GP14 : sortie PWM → MOSFET → ligne C (coque)
const int  PIN_FREQ_IN    = 2;    // GP2  : entrée interruption (ligne B, détection freq)
const int  PIN_BUTTON     = 16;   // GP16 : entrée digitalRead (ligne B via filtre RC)

// =============================================================================
// FRÉQUENCES DE RÉFÉRENCE (Hz)
// =============================================================================

const unsigned int FREQ_NEUTRE  = 20000;  // 20 kHz — coque, piste
const unsigned int FREQ_VALID_A = 25000;  // 25 kHz — cuirasse tireur A
const unsigned int FREQ_VALID_B = 40000;  // 40 kHz — cuirasse tireur B
const unsigned int TOLERANCE    = 2000;   // ±2 kHz

// =============================================================================
// PARAMÈTRES DE MESURE
// =============================================================================

const unsigned int MEASURE_WINDOW_MS = 50;    // fenêtre de comptage (ms)
const unsigned int DISPLAY_PERIOD_MS = 200;   // affichage série (ms)
const unsigned int DEBOUNCE_MS       = 5;     // anti-rebond bouton (ms)

// =============================================================================
// VARIABLES PARTAGÉES AVEC L'ISR
// =============================================================================

volatile unsigned long pulseCount = 0;

// =============================================================================
// VARIABLES D'ÉTAT
// =============================================================================

// Bouton
bool     buttonPressed      = false;   // état courant du bouton
bool     lastButtonState    = false;   // état précédent (pour détection de front)
unsigned long buttonChangeTime = 0;    // timestamp du dernier changement (debounce)

// Mesure de fréquence
unsigned long measuredFreqHz   = 0;
unsigned long lastMeasureTime  = 0;
bool          measuring        = false;  // true = on est en train de compter

// Dwell time (durée d'appui du bouton)
unsigned long buttonPressStart = 0;
unsigned long dwellTimeMs      = 0;

// Affichage
unsigned long lastDisplayTime  = 0;

// Statistiques de touche
unsigned long touchCount       = 0;

// =============================================================================
// ISR — compte chaque front montant sur GP2
// =============================================================================

void countPulse() {
    pulseCount++;
}

// =============================================================================
// Classification de la fréquence mesurée
// =============================================================================

const char* classifyFrequency(unsigned long freq) {
    if (freq < 500)
        return "AUCUNE (blanche)";
    if (freq >= FREQ_NEUTRE  - TOLERANCE && freq <= FREQ_NEUTRE  + TOLERANCE)
        return "NEUTRE  (20 kHz)";
    if (freq >= FREQ_VALID_A - TOLERANCE && freq <= FREQ_VALID_A + TOLERANCE)
        return "VALID_A (25 kHz)";
    if (freq >= FREQ_VALID_B - TOLERANCE && freq <= FREQ_VALID_B + TOLERANCE)
        return "VALID_B (40 kHz)";
    return "INCONNUE";
}

// =============================================================================
// Résultat de la touche (logique d'arbitrage simplifiée)
// =============================================================================

const char* touchResult(unsigned long freq) {
    if (freq < 500)
        return ">>> TOUCHE BLANCHE (non-valide) <<<";
    if (freq >= FREQ_NEUTRE  - TOLERANCE && freq <= FREQ_NEUTRE  + TOLERANCE)
        return "--- Pas de lumiere (coque/piste) ---";
    if (freq >= FREQ_VALID_A - TOLERANCE && freq <= FREQ_VALID_A + TOLERANCE)
        return "*** TOUCHE VALIDE sur tireur A ! ***";
    if (freq >= FREQ_VALID_B - TOLERANCE && freq <= FREQ_VALID_B + TOLERANCE)
        return "*** TOUCHE VALIDE sur tireur B ! ***";
    return "??? Frequence inconnue ???";
}

// =============================================================================
// Configuration du PWM hardware (signal carré exact)
// =============================================================================

uint pwmSliceNeutre = 0;

void setupPWM(uint pin, unsigned int freq) {
    gpio_set_function(pin, GPIO_FUNC_PWM);

    uint sliceNum = pwm_gpio_to_slice_num(pin);
    uint32_t clock_freq = clock_get_hz(clk_sys);  // 125 MHz
    uint32_t wrap = clock_freq / freq;

    pwm_config config = pwm_get_default_config();
    pwm_config_set_clkdiv(&config, 1.0f);
    pwm_config_set_wrap(&config, wrap - 1);
    pwm_init(sliceNum, &config, false);

    // Duty cycle 50% → signal carré
    pwm_set_chan_level(sliceNum, pwm_gpio_to_channel(pin), wrap / 2);

    // Démarrer le PWM
    pwm_set_enabled(sliceNum, true);

    pwmSliceNeutre = sliceNum;
}

// =============================================================================
// Lecture du bouton avec anti-rebond
// =============================================================================

bool readButtonDebounced() {
    // GP16 : HIGH = bouton au repos (B↔C fermé, signal 20 kHz filtré)
    //         LOW = bouton pressé (B↔C ouvert, condensateur déchargé)
    bool rawState = !digitalRead(PIN_BUTTON);  // inversé : LOW = pressé → true

    if (rawState != lastButtonState) {
        buttonChangeTime = millis();
    }
    lastButtonState = rawState;

    if ((millis() - buttonChangeTime) >= DEBOUNCE_MS) {
        return rawState;
    }
    return buttonPressed;  // pas encore stabilisé, garder l'état précédent
}

// =============================================================================
// SETUP
// =============================================================================

void setup() {
    Serial.begin(115200);
    delay(3000);

    // --- LED intégrée ---
    pinMode(LED_BUILTIN, OUTPUT);
    digitalWrite(LED_BUILTIN, HIGH);

    // --- Génération Freq_NEUTRE sur GP14 (via MOSFET → ligne C) ---
    setupPWM(PIN_PWM_NEUTRE, FREQ_NEUTRE);

    // --- Détection fréquence sur GP2 (interruption RISING) ---
    pinMode(PIN_FREQ_IN, INPUT);
    attachInterrupt(digitalPinToInterrupt(PIN_FREQ_IN), countPulse, RISING);

    // --- Détection bouton sur GP16 (filtre RC, digitalRead) ---
    pinMode(PIN_BUTTON, INPUT);  // pas de pull-up/pull-down interne, le RC s'en charge

    // --- En-tête ---
    Serial.println("=====================================================");
    Serial.println("  Phase 1.5 — Detection bouton + classification");
    Serial.println("=====================================================");
    Serial.println("  GP14 : PWM 20 kHz → MOSFET → ligne C (coque)");
    Serial.println("  GP2  : detection frequence (interruption RISING)");
    Serial.println("  GP16 : detection bouton (filtre RC, digitalRead)");
    Serial.println("-----------------------------------------------------");
    Serial.println("  Bouton au repos : GP16 = HIGH (signal 20 kHz filtre)");
    Serial.println("  Bouton presse   : GP16 = LOW  (condensateur decharge)");
    Serial.println("-----------------------------------------------------");
    Serial.println("  En attente d'appui sur le bouton du fleuret...");
    Serial.println("=====================================================");
    Serial.println();

    lastMeasureTime = millis();
    lastDisplayTime = millis();
}

// =============================================================================
// LOOP
// =============================================================================

void loop() {
    unsigned long now = millis();

    // -----------------------------------------------------------------
    // 1. Lire l'état du bouton (avec anti-rebond)
    // -----------------------------------------------------------------
    bool currentPressed = readButtonDebounced();

    // -----------------------------------------------------------------
    // 2. Détection du front descendant (bouton vient d'être pressé)
    // -----------------------------------------------------------------
    if (currentPressed && !buttonPressed) {
        // Front : bouton vient d'être pressé
        buttonPressStart = now;
        measuring = true;

        // Reset du compteur pour une mesure propre
        noInterrupts();
        pulseCount = 0;
        interrupts();
        lastMeasureTime = now;

        Serial.println("[BOUTON] Presse ! Mesure en cours...");
    }

    // -----------------------------------------------------------------
    // 3. Détection du front montant (bouton vient d'être relâché)
    // -----------------------------------------------------------------
    if (!currentPressed && buttonPressed) {
        // Front : bouton vient d'être relâché
        dwellTimeMs = now - buttonPressStart;
        measuring = false;

        // Dernière mesure
        noInterrupts();
        unsigned long count = pulseCount;
        pulseCount = 0;
        interrupts();

        unsigned long elapsed = now - lastMeasureTime;
        if (elapsed > 0) {
            measuredFreqHz = (count * 1000UL) / elapsed;
        }

        // Afficher le résultat de la touche
        touchCount++;
        Serial.println("-----------------------------------------------------");
        Serial.print("[TOUCHE #");
        Serial.print(touchCount);
        Serial.print("]  Freq: ");
        Serial.print(measuredFreqHz);
        Serial.print(" Hz | ");
        Serial.print(classifyFrequency(measuredFreqHz));
        Serial.print(" | Dwell: ");
        Serial.print(dwellTimeMs);
        Serial.println(" ms");

        Serial.print("  Resultat: ");
        Serial.println(touchResult(measuredFreqHz));

        // Vérification dwell time FIE (15 ms minimum)
        if (dwellTimeMs < 15) {
            Serial.println("  /!\\ Dwell time < 15 ms (insuffisant pour la FIE)");
        }
        Serial.println("-----------------------------------------------------");
        Serial.println();
    }

    // -----------------------------------------------------------------
    // 4. Pendant que le bouton est pressé : mesure continue
    // -----------------------------------------------------------------
    if (measuring && (now - lastMeasureTime >= MEASURE_WINDOW_MS)) {
        noInterrupts();
        unsigned long count = pulseCount;
        pulseCount = 0;
        interrupts();

        unsigned long elapsed = now - lastMeasureTime;
        measuredFreqHz = (count * 1000UL) / elapsed;
        lastMeasureTime = now;
    }

    // -----------------------------------------------------------------
    // 5. Mettre à jour l'état du bouton
    // -----------------------------------------------------------------
    buttonPressed = currentPressed;

    // -----------------------------------------------------------------
    // 6. Affichage périodique de l'état
    // -----------------------------------------------------------------
    if (now - lastDisplayTime >= DISPLAY_PERIOD_MS) {
        lastDisplayTime = now;

        if (buttonPressed) {
            // Bouton pressé : afficher la fréquence en temps réel
            Serial.print("[MESURE] Freq: ");
            Serial.print(measuredFreqHz);
            Serial.print(" Hz | ");
            Serial.print(classifyFrequency(measuredFreqHz));
            Serial.print(" | Dwell: ");
            Serial.print(now - buttonPressStart);
            Serial.println(" ms");

            // LED clignote pendant la mesure
            digitalWrite(LED_BUILTIN, (now / 100) % 2 ? HIGH : LOW);
        } else {
            // Bouton au repos : affichage discret
            Serial.print("[REPOS] GP16=");
            Serial.print(digitalRead(PIN_BUTTON) ? "HIGH" : "LOW");
            Serial.print(" | GP2 freq: ");
            Serial.print(measuredFreqHz);
            Serial.println(" Hz");

            // LED allumée fixe au repos
            digitalWrite(LED_BUILTIN, HIGH);
        }
    }
}

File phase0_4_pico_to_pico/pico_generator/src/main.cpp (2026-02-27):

// =============================================================================
// GÉNÉRATEUR DE SIGNAL — Raspberry Pi Pico W
// Projet : Escrime sans fil — Phase 0.4 (Pico → Pico, sans GND commun)
// =============================================================================
//
// RÔLE : Génère un signal carré sur GPIO 15 via PWM hardware du RP2040.
//        tone() est imprécis sur le Pico W aux hautes fréquences (~14-16 kHz
//        au lieu de 20 kHz). Le PWM hardware est exact.
//
// CÂBLAGE :
//   GPIO 15  → un seul fil vers GPIO 2 du Pico récepteur
//   GND      → NE PAS connecter au récepteur
//   VBUS     → alimentation 5V depuis adaptateur secteur via multiprise
//
// LED INTÉGRÉE :
//   LED allumée en continu  → signal actif
//   LED clignotante lente   → signal désactivé
//
// COMMANDES SÉRIE (optionnel, si FTDI branché) :
//   t → bascule signal ON/OFF
//   1 → 20 kHz (NEUTRE)
//   2 → 25 kHz (VALID_A)
//   3 → 40 kHz (VALID_B)
// =============================================================================

#include <Arduino.h>
#include <hardware/pwm.h>
#include <hardware/clocks.h>

// --- Broche de sortie du signal ---
const uint PIN_SIGNAL_OUT = 15;

// --- Fréquences disponibles ---
const unsigned int FREQ_NEUTRE  = 1000;  // 20 kHz — exact
const unsigned int FREQ_VALID_A = 25000;  // 25 kHz — exact
const unsigned int FREQ_VALID_B = 40000;  // 40 kHz — exact

// --- État courant ---
bool          signalActif  = true;
unsigned int  freqActuelle = FREQ_NEUTRE;
uint          sliceNum     = 0;

// --- Timing ---
unsigned long dernierClignotement = 0;
bool          etatLed             = false;
unsigned long dernierAffichage    = 0;

// ---------------------------------------------------------------------------
// Configure le PWM hardware pour une fréquence exacte (signal carré 50%)
// RP2040 clock = 125 MHz
// freq = 125000000 / (diviser * wrap)
// Pour un signal carré : duty = wrap / 2
// ---------------------------------------------------------------------------
void configurerPWM(unsigned int freq) {
  // Calcul du wrap pour cette fréquence (diviser = 1)
  // wrap = clock_freq / freq
  uint32_t clock_freq = clock_get_hz(clk_sys);  // 125 MHz
  uint32_t wrap = clock_freq / freq;

  // Configurer le slice PWM
  sliceNum = pwm_gpio_to_slice_num(PIN_SIGNAL_OUT);

  pwm_config config = pwm_get_default_config();
  pwm_config_set_clkdiv(&config, 1.0f);       // pas de division, pleine vitesse
  pwm_config_set_wrap(&config, wrap - 1);      // période
  pwm_init(sliceNum, &config, false);          // ne pas démarrer encore

  // Duty cycle 50% → signal carré
  pwm_set_chan_level(sliceNum, pwm_gpio_to_channel(PIN_SIGNAL_OUT), wrap / 2);
}

// ---------------------------------------------------------------------------
void demarrerPWM() {
  pwm_set_enabled(sliceNum, true);
}

void arreterPWM() {
  pwm_set_enabled(sliceNum, false);
  gpio_put(PIN_SIGNAL_OUT, 0);  // forcer le pin à LOW
}

// ---------------------------------------------------------------------------
const char* nomFreq(unsigned int freq) {
  if (freq == FREQ_NEUTRE)  return "NEUTRE  (20 kHz)";
  if (freq == FREQ_VALID_A) return "VALID_A (25 kHz)";
  if (freq == FREQ_VALID_B) return "VALID_B (40 kHz)";
  return "INCONNUE";
}

// ---------------------------------------------------------------------------
void activerSignal() {
  configurerPWM(freqActuelle);
  demarrerPWM();
  digitalWrite(LED_BUILTIN, HIGH);
  signalActif = true;
  Serial.print("[SIGNAL ON]  Frequence : ");
  Serial.println(nomFreq(freqActuelle));
}

void desactiverSignal() {
  arreterPWM();
  signalActif = false;
  Serial.println("[SIGNAL OFF]");
}

void changerFrequence(unsigned int nouvelleFreq) {
  freqActuelle = nouvelleFreq;
  if (signalActif) {
    configurerPWM(freqActuelle);
    demarrerPWM();
  }
  Serial.print("[FREQ] ");
  Serial.println(nomFreq(freqActuelle));
}

// ---------------------------------------------------------------------------
// SETUP
// ---------------------------------------------------------------------------
void setup() {
  Serial.begin(115200);
  delay(3000);

  // Configurer GPIO 15 comme sortie PWM
  gpio_set_function(PIN_SIGNAL_OUT, GPIO_FUNC_PWM);
  pinMode(LED_BUILTIN, OUTPUT);

  // Démarrage du signal à 20 kHz
  activerSignal();

  Serial.println("=========================================");
  Serial.println("  GENERATEUR — Pico W  (phase0_4)");
  Serial.println("  PWM hardware (exact, pas tone())");
  Serial.println("=========================================");
  Serial.println("  Broche signal : GPIO 15");
  Serial.println("  Alimentation  : adaptateur secteur");
  Serial.println("  GND commun    : NON");
  Serial.println("-----------------------------------------");
  Serial.println("  t -> ON/OFF | 1=20k | 2=25k | 3=40k");
  Serial.println("=========================================");
  Serial.print("  Etat initial : ");
  Serial.println(nomFreq(freqActuelle));
  Serial.println();

  dernierAffichage = millis();
}

// ---------------------------------------------------------------------------
// LOOP
// ---------------------------------------------------------------------------
void loop() {

  // --- Commandes série ---
  if (Serial.available() > 0) {
    char cmd = Serial.read();
    switch (cmd) {
      case 't':
        signalActif ? desactiverSignal() : activerSignal();
        break;
      case '1': changerFrequence(FREQ_NEUTRE);  break;
      case '2': changerFrequence(FREQ_VALID_A); break;
      case '3': changerFrequence(FREQ_VALID_B); break;
    }
  }

  // --- LED : allumée si signal actif, clignote sinon ---
  if (!signalActif) {
    unsigned long now = millis();
    if (now - dernierClignotement >= 500) {
      dernierClignotement = now;
      etatLed = !etatLed;
      digitalWrite(LED_BUILTIN, etatLed ? HIGH : LOW);
    }
  }

  // --- Affichage périodique ---
  unsigned long now = millis();
  if (now - dernierAffichage >= 2000) {
    dernierAffichage = now;
    Serial.print("[STATUS] ");
    Serial.print(signalActif ? "ON" : "OFF");
    Serial.print(" | ");
    Serial.println(nomFreq(freqActuelle));
  }
}

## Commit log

2026-02-18 Initial commit: project plan for wireless fencing scoring system
    Document the full architecture for a wireless foil fencing scoring system
    using Raspberry Pi Pico 2W with frequency-based touch detection to replace
    the common ground of wired systems.
2026-02-19 Phase 0.1-0.3: validate frequency detection without common GND
    - Add phase0_1 (interrupt-based freq detection on Mega, same board)
    - Add phase0_2 (multi-frequency classification on Mega, same board)
    - Add phase0_3 (Mega generator + Pico W receiver, no common GND)
    - Key result: signal detection works across isolated power supplies
    (Mega on mains adapter, Pico W on Mac battery via USB)
    - Update PROJECT_PLAN.md with all findings:
    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
2026-02-19 Phase 0.4: validate Pico-to-Pico detection with 10kΩ pull-down
    - Add phase0_4 Pico W generator (PWM hardware, not tone()) and receiver
    - Key findings:
    - tone() is inaccurate on Pico W at high frequencies (~14-16 kHz vs 20 kHz)
    - PWM hardware (hardware/pwm.h) generates exact frequencies
    - Without pull-down: only ~80% of rising edges detected (~16 kHz read)
    - Internal pull-down (50kΩ): insufficient
    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
2026-02-24 Phase 1: document cuirasse capacitive load problem and buffer solution
    Tests with body wire + cuirasse reveal GPIO cannot drive the capacitive
    load at 20 kHz (5-7 kHz detected on chair, 10-19 kHz in air vs 20 kHz
    on direct wire). Root cause: parasitic capacitance of the large conductive
    surface. Solution: MOSFET buffer (2N7000) between GPIO and cuirasse,
    powered by VBUS 5V. Awaiting components to validate.
    [main.cpp]
2026-02-25 Phase 1: validate MOSFET 2N7000 buffer with 100Ω pull-up for cuirasse
    Buffer circuit (2N7000 + 100Ω pull-up to VBUS 5V) resolves capacitive
    load problem on cuirasse. 20 kHz detected reliably through body wire +
    foil touching cuirasse on chair. 10kΩ pull-up was too weak (only 20-50 Hz
    on drain). Signal detected even with button unpressed — expected behavior,
    requires dedicated GPIO for button state detection (GP20).
    [main.cpp]
2026-02-25 Phase 1.5: discover B↔C parasitic coupling, revise architecture to 3-pin design
    Test with RC filter on GP16 revealed that the MOSFET buffer signal on
    line C (20kHz, 5V/50mA) bleeds into line B through capacitive coupling
    inside the foil. GP2 sees ~20kHz permanently regardless of button state.
    RC filter approach abandoned. Architecture revised from 4 pins to 3 pins:
    - GP14 (PWM) → line A → Freq_VALID on cuirasse (via MOSFET buffer)
    - GP2 (GPIO IN + 10kΩ pull-down) → line B → frequency detection
    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
2026-02-26 Update architecture: complete circuit with 3 MOSFETs, add GP15, rename to Mode Simple / Mode Time-Division
    - Add GP15 (MOSFET C) to cut pull-up power during button detection phase
    - Full circuit: GP14→MOSFET A (line A), GP17→MOSFET B + GP15→MOSFET C (line C), GP16 (button read), GP2 (freq detect)
    - Circuit is wired once; switching Mode Simple → Mode Time-Division is software only
    - In Mode Simple: GP15=LOW, GP17=LOW (emission circuit inactive)
    - In Mode Time-Division: GP15+GP17 control 9ms emit / 1ms detect cycle
    - Rename Option 2 → Mode Simple, Option 3 → Mode Time-Division
2026-02-27 Phase 1.6-1.7: button DC validated, GP16 crash fixed, foil attenuation discovered — frequencies must be lowered to 1-3 kHz
    - Phase 1.6 DONE: button detection via DC on GP16 works reliably
    - Phase 1.7 partial: GP16 5V crash fixed (10kΩ series resistor),
    interrupt avalanche fixed (attach/detach by button state),
    foil internal wire attenuation discovered (BLOCKING)
    - Foil parasitic capacitance (~10nF) shunts AC signal to blade:
    20kHz → only ~1700 Hz detected, frequencies must drop to 1-3 kHz
    - Add CLAUDE.md (LLM context file) with all discoveries
    - Add phase1_6_button_dc/ test code (diagnostic ISR)
    - Add KiCad schematic project (wireless_fencing_fencer/, in progress)
    - Update PROJECT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
    [wireless_fencing_fencer.kicad_pcb, wireless_fencing_fencer.kicad_sch]
